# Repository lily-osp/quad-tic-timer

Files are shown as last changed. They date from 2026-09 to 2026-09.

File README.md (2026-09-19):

# quad-tic-timer

A single ATtiny85 that puts out four synchronized tick channels from one knob. No 555s, no extra oscillators. You turn the pot and all four outputs speed up or slow down together, keeping their ratios exact.

It was built for a small robotics project that needed several timing references at once without adding boards or trimming four separate RC circuits.

<p align="center">
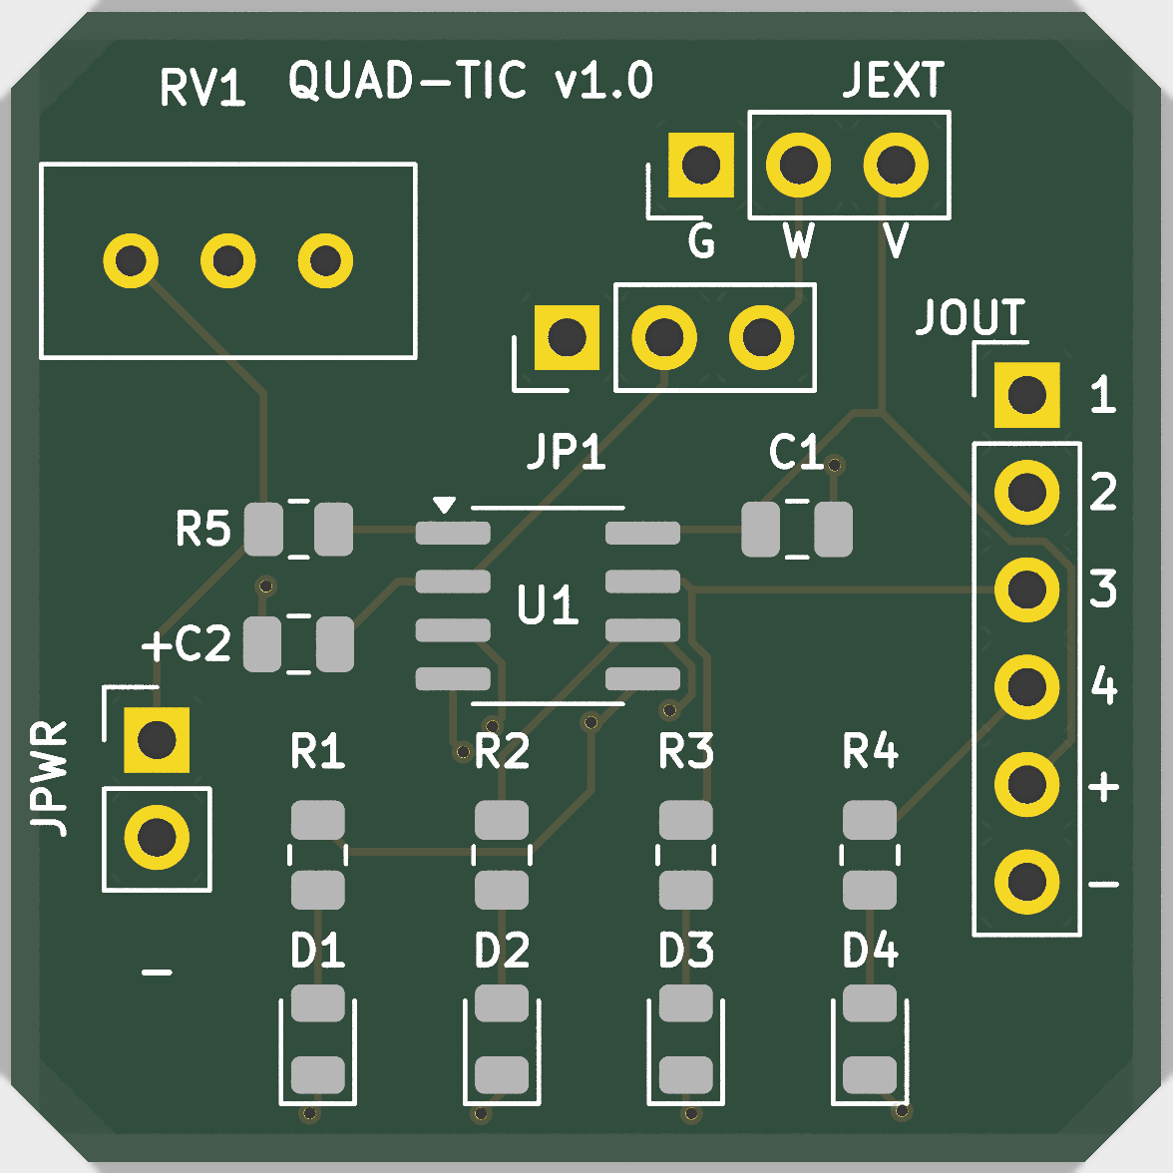
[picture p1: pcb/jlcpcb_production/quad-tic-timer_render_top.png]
Quad-Tic-Timer Top 3D Render
  
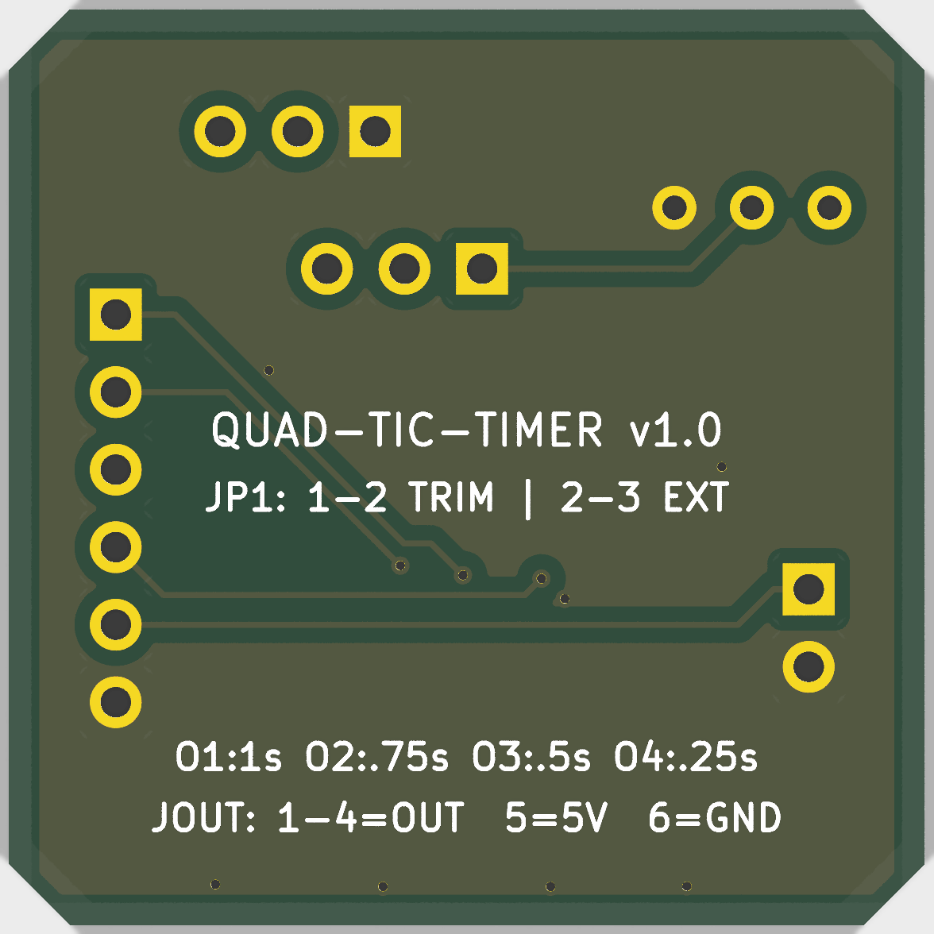
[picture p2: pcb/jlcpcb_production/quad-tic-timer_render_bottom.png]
Quad-Tic-Timer Bottom 3D Render
  
</p>

## What it does

Four active-HIGH pulse outputs, 10 ms wide:

| Output | Pin | Nominal (pot centered) | Full CCW | Full CW |
|---|-----|---|---|---|
| o1 | PB0 | 1.00 s/tic | 0.20 s | 5.00 s |
| o2 | PB1 | 0.75 s/tic | 0.15 s | 3.75 s |
| o3 | PB2 | 0.50 s/tic | 0.10 s | 2.50 s |
| o4 | PB4 | 0.25 s/tic | 0.05 s | 1.25 s |

The pot sets one global scale factor `k` from 0.2 to 5.0. Center detent is 1.0x. The mapping is exponential, `k = 5^((adc-512)/512)`, so the slow end stays usable instead of bunching up the way a linear map would.

Timing is phase-accurate: each channel schedules its next edge as `next += period`, so error never accumulates. Ratios stay exact even while you turn the knob. Absolute accuracy follows the ATtiny85 internal oscillator, roughly 1% after factory calibration. That is an order of magnitude better than a 555 RC stage and fine for sequencing work.

## Wiring

```
ATtiny85 (SOIC-8/DIP-8, 8 MHz internal)
VCC -- 100nF -- GND (as close to the chip as possible)
PB3 -- pot wiper (10k 10-turn lin, ends to VCC/GND) + 10nF to GND
PB0 -- o1
PB1 -- o2
PB2 -- o3
PB4 -- o4
RST -- 10k to VCC (leave free for ISP)
```

Outputs drive LEDs through 330R or logic inputs directly. Total draw is a few mA plus loads.

Pot: 10k linear 10-turn precision type. Panel version is Bourns 3590S-1-103L with an H-22 turns-counting dial (5 turns from center to either end). If board space is tight, use the 25-turn trimmer Bourns 3296W-103 instead — same wiring, smaller, adjusted with a screwdriver. Either way center (5 turns from either stop) is the nominal 1.0x rate.

BOM: 1x ATtiny85, 1x 10k 10-turn pot, 1x 100nF, 1x 10nF, 1x 10k resistor. Nothing else.

## Build and flash

ATTinyCore, ATtiny85, 8 MHz internal, LTO enabled.

```bash
arduino-cli compile --fqbn ATTinyCore:avr:attinyx5:chip=85,clock=8internal quad-tic-timer.ino
avrdude -c usbasp -p t85 -U flash:w:quad-tic-timer.ino.hex:i -U lfuse:w:0xe2:m -U hfuse:w:0xdf:m -U efuse:w:0xff:m
```

Or open `quad-tic-timer.ino` in the Arduino IDE (sketchbook is at `microcontrollers/00_toolchain/arduino-ide`) and flash with USBasp / Arduino-as-ISP. Keep the reset pin enabled.

Check it with four LEDs first. Center the pot, o1 should blink once per second, o4 four times per second. Turn fully left and o1 runs at 5 Hz. Turn fully right and o1 takes 5 s per blink.

## Tuning

Two constants matter in `quad-tic-timer.ino`:

- `TIC_US` (10 ms) — shorten to 2–5 ms if the receiving logic is edge-sensitive and fast, lengthen to 20–50 ms for relays or optocouplers.
- The `> 2` deadband and 50 ms pot poll — tuned for a 10-turn pot (about 100 ADC steps per turn). Raise the deadband to 6–8 in a noisy supply, lower the poll to 20 ms if you want a snappier knob.

Pot reads are averaged over 16 samples and referenced to VCC, so the reading is ratiometric and supply drift largely cancels out. One ADC step is about 0.3% rate change at mid-scale, roughly a third of a turn feel on a 10-turn pot.

## Where it fits

- Robot gait and sequencer clocks: one channel steps the main loop, the faster channels drive leg phases, sensor polls, or status blinks from the same tempo.
- Sensor scheduler: poll slow sensors on o1/o2, fast IMU or encoder sampling on o3/o4, all slowing together in low-power mode.
- Servo/stepper test bench: sweep the whole timing tree with one hand while watching mechanics respond.
- Automation and stage props: trigger solenoids, pumps, or lights at related intervals without a full PLC.
- Camera trap / timelapse: o1 fires the shutter, o4 wakes the focus/metering chain just before.
- Music and kinetic art: clock dividers for drum triggers, solenoids, or LED chases.

Any place that currently uses two to four 555s for related rates is a candidate. This replaces them with one 8-pin chip and holds ratio over temperature far better than RC timing.

## Limits

- Not a reference clock. The internal oscillator drifts about 1–2% with voltage and temperature. Ratios are exact, absolute rate is not.
- Shortest period is 50 ms on o4 at full CCW. The 10 ms pulse is then 20% duty, which is fine for logic but too wide for some edge counters. Adjust `TIC_US` if that matters.
- ADC noise on a long wiper wire can make the tempo wander at the extremes. Keep the wiper lead short and keep the 10nF cap.

If you later need crystal accuracy, port the sketch unchanged to an ATmega328P Nano clone or STM32 Blue Pill and set the same four pins. For lab-grade absolute rate, feed a DS3231 1 Hz TCXO into a spare input and discipline `k` against it.

## Files

```
quad-tic-timer/
  quad-tic-timer.ino  firmware, ATtiny85, single sketch, no dependencies
  README.md           this file
  .gitignore          Arduino/AVR/PlatformIO ignores
  pcb/                production 30x30mm KiCad 9 PCB & JLCPCB manufacturing package
    quad-tic-timer.kicad_pcb
    quad-tic-timer.kicad_sch
    quad-tic-timer-drc.rpt
    quad-tic-timer-erc.rpt
    jlcpcb_production/  Gerbers, BOM, CPL, 3D renders
```

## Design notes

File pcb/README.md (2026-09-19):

# Quad-Tic-Timer: ATtiny85 Synchronized Robotic Pulse Generator PCB

A 30x30mm 2-layer KiCad 9 development board for the **Quad-Tic-Timer** firmware. Driven by an **Atmel ATtiny85-20SU**, it provides four synchronized phase-accurate pulse outputs scaled exponentially by a single precision 10-turn control pot.

Designed and verified using the **pcb** skill with full **KiCad 9** headless tooling and production-ready **JLCPCB** fabrication deliverables.

---

## 📌 3D Render Previews

| Top Side (Components & Telemetry) | Bottom Side (Ground Plane & Labeling) |
| :---: | :---: |
| Top 3D Render | Bottom 3D Render |

---

## ⚡ Hardware Architecture & Features

- **Microcontroller**: Microchip / Atmel **ATtiny85-20SU** (SOIC-8, 8 MHz internal calibrated RC oscillator).
- **Quad Synchronized Pulse Outputs**:
  - `O1` (PB0 / Pin 5): 1.00 s/tic nominal (0.20 s – 5.00 s range)
  - `O2` (PB1 / Pin 6): 0.75 s/tic nominal (0.15 s – 3.75 s range)
  - `O3` (PB2 / Pin 7): 0.50 s/tic nominal (0.10 s – 2.50 s range)
  - `O4` (PB4 / Pin 3): 0.25 s/tic nominal (0.05 s – 1.25 s range)
- **Dual Potentiometer Sourcing**:
  - **Onboard Trimmer**: Bourns 3296W vertical 10k 25-turn potentiometer (`RV1`).
  - **External Pot Header**: 1x03 2.54mm pin header (`JEXT`) for panel-mount 10-turn pots (Bourns 3590S).
  - **Source Select Jumper**: 1x03 2.54mm header (`JP1`). Jumper pins 1-2 for onboard trimmer, 2-3 for external pot.
- **Power & Conditioning**:
  - `C1` (100nF 0805): Dedicated VCC decoupling placed within 2 mm of U1 pin 8.
  - `C2` (10nF 0805): Low-pass noise filter on ADC3 wiper input (U1 pin 2).
  - `R5` (10k 0805): Pull-up on RESET (pin 1) keeping reset line high while leaving it ISP-programmable.
  - `JPWR` (1x02): 5V DC input.
- **Visual Status Telemetry**:
  - Four independent 0805 LEDs (`D1`–`D4`) driven through 1kΩ ballast resistors (`R1`–`R4`) indicating pulse ticks on each channel.
- **Output Interface**:
  - `JOUT` (1x06 2.54mm header): Exposes `O1`, `O2`, `O3`, `O4`, `VCC`, and `GND`.
- **Board Specifications**:
  - Form factor: **30.0 mm x 30.0 mm** with 2.0 mm corner chamfers.
  - Layer stack: 2-layer (1.6 mm FR4, 1 oz Cu, HASL lead-free).
  - Bottom layer: Continuous low-impedance ground plane (`B.Cu`).
  - Free prototype rule compliant (well within JLCPCB 100x100mm bounds).

---

## 🗂️ Project Deliverables (Zero Bloat)

```text
quad-tic-timer/pcb/
├── README.md                      # Comprehensive technical hardware documentation
├── fp-info-cache                  # KiCad footprint library cache
├── quad-tic-timer.kicad_pro       # KiCad 9 project file
├── quad-tic-timer.kicad_prl       # KiCad 9 local settings file
├── quad-tic-timer.kicad_sch       # KiCad 9 complete schematic with embedded symbols
├── quad-tic-timer.kicad_pcb       # KiCad 9 fully routed board (0 DRC, 0 unconnected)
├── quad-tic-timer-drc.rpt         # Official KiCad DRC report (0 errors, 0 warnings)
├── quad-tic-timer-erc.rpt         # Official KiCad ERC report (0 errors, 0 warnings)
└── jlcpcb_production/             # Turn-key manufacturing archive
    ├── quad-tic-timer_gerber_jlcpcb.zip  # RS-274X Gerbers + Excellon NC drills
    ├── quad-tic-timer_bom_jlcpcb.csv     # Bill of Materials formatted for JLCPCB
    ├── quad-tic-timer_cpl_jlcpcb.csv     # Pick-and-place centroid coordinate file
    ├── quad-tic-timer_render_top.png     # Photorealistic 3D top render
    └── quad-tic-timer_render_bottom.png  # Photorealistic 3D bottom render
```

---

## ⚡ Bill of Materials (BOM)

| Designator | Description | Footprint | LCSC Part # | Qty |
| :--- | :--- | :--- | :--- | :--- |
| **U1** | ATtiny85-20SU 8-bit AVR Microcontroller | SOIC-8_3.9x4.9mm_P1.27mm | C44533 | 1 |
| **RV1** | 10k Precision Multi-turn Trimpot | Bourns_3296W_Vertical | C180126 | 1 |
| **C1** | 100nF 50V Ceramic Capacitor | C_0805_2012Metric | C49678 | 1 |
| **C2** | 10nF 50V Ceramic Capacitor | C_0805_2012Metric | C1710 | 1 |
| **R5** | 10kΩ 1% 1/8W Pullup Resistor | R_0805_2012Metric | C17414 | 1 |
| **R1–R4** | 1kΩ 1% 1/8W LED Current-Limiters | R_0805_2012Metric | C17513 | 4 |
| **D1–D4** | Green LED Indicators | LED_0805_2012Metric | C2297 | 4 |
| **JPWR** | 1x02 2.54mm Pin Header (Power In) | PinHeader_1x02_P2.54mm_Vertical | C2241 | 1 |
| **JP1** | 1x03 2.54mm Pin Header (Pot Select) | PinHeader_1x03_P2.54mm_Vertical | C2242 | 1 |
| **JEXT** | 1x03 2.54mm Pin Header (Ext Pot) | PinHeader_1x03_P2.54mm_Vertical | C2242 | 1 |
| **JOUT** | 1x06 2.54mm Pin Header (Signal Out) | PinHeader_1x06_P2.54mm_Vertical | C2245 | 1 |

---

## 🔍 Verification & Quality Assurance

1. **Pre-flight Placement Validation**:
   - Courtyard overlaps: **0 collisions**
   - Minimum edge clearance: **> 0.5 mm** across all footprints
2. **Electrical Rules Check (ERC)**:
   - `quad-tic-timer-erc.rpt`: **0 errors, 0 warnings**
   - All 47 electrical nodes matched 1:1 with PCB netlist
3. **Design Rules Check (DRC)**:
   - `quad-tic-timer-drc.rpt`: **0 errors, 0 warnings, 0 unconnected items**
   - Minimum track width: 0.25 mm (well above 0.15 mm JLCPCB limit)
   - Minimum track clearance: 0.20 mm
   - Minimum via drill/diameter: 0.30 mm / 0.60 mm
4. **Manufacturing Package Integrity**:
   - Drill Census: 27 drilled holes (2 files, PTH + NPTH)
   - Board outline verified on `Edge_Cuts` (`.gm1`)
   - Gerbers tested and packaged into `quad-tic-timer_gerber_jlcpcb.zip` ready for one-click upload.

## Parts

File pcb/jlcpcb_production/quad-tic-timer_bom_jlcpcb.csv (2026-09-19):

Refs | Value | Footprint | Qty | DNP
C1 | 100n | Capacitor_SMD:C_0805_2012Metric | 1
C2 | 10n | Capacitor_SMD:C_0805_2012Metric | 1
D1 | LED-O1 | LED_SMD:LED_0805_2012Metric | 1
D2 | LED-O2 | LED_SMD:LED_0805_2012Metric | 1
D3 | LED-O3 | LED_SMD:LED_0805_2012Metric | 1
D4 | LED-O4 | LED_SMD:LED_0805_2012Metric | 1
JEXT | EXT-POT | Connector_PinHeader_2.54mm:PinHeader_1x03_P2.54mm_Vertical | 1
JOUT | OUT | Connector_PinHeader_2.54mm:PinHeader_1x06_P2.54mm_Vertical | 1
JP1 | POT-SEL | Connector_PinHeader_2.54mm:PinHeader_1x03_P2.54mm_Vertical | 1
JPWR | PWR | Connector_PinHeader_2.54mm:PinHeader_1x02_P2.54mm_Vertical | 1
R1 | 1k | Resistor_SMD:R_0805_2012Metric | 1
R2 | 1k | Resistor_SMD:R_0805_2012Metric | 1
R3 | 1k | Resistor_SMD:R_0805_2012Metric | 1
R4 | 1k | Resistor_SMD:R_0805_2012Metric | 1
R5 | 10k | Resistor_SMD:R_0805_2012Metric | 1
RV1 | 10k | Potentiometer_THT:Potentiometer_Bourns_3296W_Vertical | 1
U1 | ATtiny85 | Package_SO:SOIC-8_3.9x4.9mm_P1.27mm | 1

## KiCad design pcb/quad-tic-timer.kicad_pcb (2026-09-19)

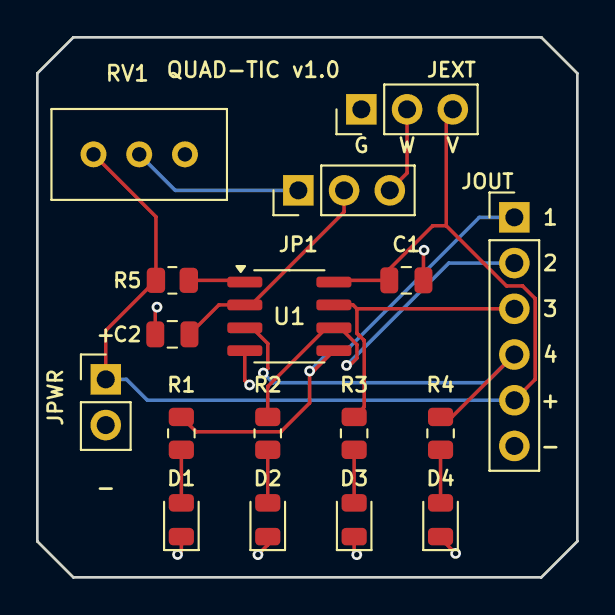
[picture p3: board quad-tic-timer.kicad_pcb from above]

Board: 2 copper layers, 30.0 x 30.0 mm, 17 parts (0 on the bottom side), 14 nets.

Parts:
C1: 100n; C_0805_2012Metric
C2: 10n; C_0805_2012Metric
D1: O1; LED_0805_2012Metric
D2: O2; LED_0805_2012Metric
D3: O3; LED_0805_2012Metric
D4: O4; LED_0805_2012Metric
JEXT: EXT-POT; PinHeader_1x03_P2.54mm_Vertical
JOUT: OUT; PinHeader_1x06_P2.54mm_Vertical
JP1: POT-SEL; PinHeader_1x03_P2.54mm_Vertical
JPWR: PWR; PinHeader_1x02_P2.54mm_Vertical
R1, R2, R3, R4: 1k; R_0805_2012Metric
R5: 10k; R_0805_2012Metric
RV1: 10k; Potentiometer_Bourns_3296W_Vertical
U1: ATtiny85; SOIC-8_3.9x4.9mm_P1.27mm

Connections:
GND: C1.2, C2.1, D1.1, D2.1, D3.1, D4.1, JEXT.1, JOUT.6, JPWR.2, RV1.1, U1.4
N_EXTW: JEXT.2, JP1.3
N_LED1: D1.2, R1.2
N_LED2: D2.2, R2.2
N_LED3: D3.2, R3.2
N_LED4: D4.2, R4.2
N_POT: C2.2, JP1.2, U1.2
N_RST: R5.2, U1.1
N_RVW: JP1.1, RV1.2
O1: JOUT.1, R1.1, U1.5
O2: JOUT.2, R2.1, U1.6
O3: JOUT.3, R3.1, U1.7
O4: JOUT.4, R4.1, U1.3
VCC: C1.1, JEXT.3, JOUT.5, JPWR.1, R5.1, RV1.3, U1.8

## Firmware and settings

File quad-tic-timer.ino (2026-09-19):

// quad-tic-timer.ino - ATtiny85 4-channel ratio tic generator with single-pot global tempo
// Board: ATtiny85 @ 8MHz internal (ATTinyCore). Programmer: USBasp / Arduino-as-ISP.
// Pins: PB3/A3 <- 10k 10-turn precision pot wiper (Bourns 3590S-1-103L or 3296W trimmer),
//        PB0=o1, PB1=o2, PB2=o3, PB4=o4
//
// Nominal (pot centered): o1=1.00s, o2=0.75s, o3=0.50s, o4=0.25s per tic.
// Range: o1 = 0.2s (full CCW) .. 5.0s (full CW), others track by fixed ratio.
// Mapping is exponential: k = 5^((pot-512)/512), so mid detent = 1.0x.
// Output: 10ms active-HIGH pulse, non-blocking, phase-accurate (no drift accumulation).
#include <avr/wdt.h>

const uint8_t OUT_PINS[4] = {0, 1, 2, 4};
const uint8_t POT_PIN = A3;
const uint32_t NOM_US[4] = {1000000UL, 750000UL, 500000UL, 250000UL};
const uint32_t TIC_US = 10000UL;

uint32_t chNext[4] = {0, 0, 0, 0};
uint32_t chOff[4] = {0, 0, 0, 0};
uint32_t chPeriod[4] = {1000000UL, 750000UL, 500000UL, 250000UL};
uint16_t potFilt = 512;

uint16_t readPot() {
  uint16_t s = 0;
  for (uint8_t i = 0; i < 16; i++) s += analogRead(POT_PIN);
  return s >> 4;
}

void setup() {
  wdt_enable(WDTO_500MS);
  for (uint8_t i = 0; i < 4; i++) {
    pinMode(OUT_PINS[i], OUTPUT);
    digitalWrite(OUT_PINS[i], LOW);
    chNext[i] = micros() + NOM_US[i];
  }
}

void loop() {
  wdt_reset();
  static uint32_t lastPot = 0;
  uint32_t now = micros();

  if (millis() - lastPot > 50) {
    lastPot = millis();
    uint16_t raw = readPot();
    if (abs((int)raw - (int)potFilt) > 2) {
      potFilt = constrain(raw, 0, 1023);
      float k = pow(5.0, ((float)potFilt - 512.0) / 512.0);
      for (uint8_t i = 0; i < 4; i++)
        chPeriod[i] = (uint32_t)(NOM_US[i] * k);
    }
  }

  for (uint8_t i = 0; i < 4; i++) {
    if ((int32_t)(now - chNext[i]) >= 0) {
      digitalWrite(OUT_PINS[i], HIGH);
      chOff[i] = now + TIC_US;
      chNext[i] += chPeriod[i];
      if ((int32_t)(now - chNext[i]) >= 0) chNext[i] = now + chPeriod[i];
    }
    if (digitalRead(OUT_PINS[i]) && (int32_t)(now - chOff[i]) >= 0)
      digitalWrite(OUT_PINS[i], LOW);
  }
}
